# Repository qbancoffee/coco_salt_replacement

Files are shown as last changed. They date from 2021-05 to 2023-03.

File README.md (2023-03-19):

# Drop in replacement board for the custom SALT chip on the CoCo's

- [Installation instructions](https://github.com/qbancoffee/coco_salt_replacement/wiki/Installing-a-pepper-board)
- [View PDF version of the schematic](pepper_schematic.pdf)
- [Download the latest release](https://github.com/qbancoffee/coco_salt_replacement/releases/latest)
- [How to order from JLCPCB](#Ordering-the-board)
- [Peppers in the wild](#Peppers-In-The-Wild)

This board replaces the functionality of the SALT chip in the CoCo (CoCo 2 in my case). 
The SALT chip (Supply and Level Translator) is responsible for supply regulation, RS-232
interface, level translation, cassette read operations, and driving the cassette relay.

I designed it using available parts from JLCPCB to reduce assembly time and to bring down the cost.

## Goals
- [x] Power regulation with a switching regulator instead of a linear regulator.
- [x] RS232 interface.
- [x] Zero crossing detector to read cassette data.
- [x] Cassette relay control.

All goals were met!!!<br>
[Video testing the SALT replacement board AKA the PEPPER board](https://youtu.be/D6V6HFp6FHY)

## Layout
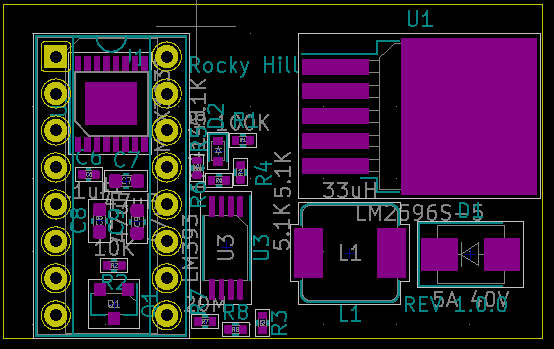
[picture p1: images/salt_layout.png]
Layout Component layout


## 3D rendering and pictures of it installed
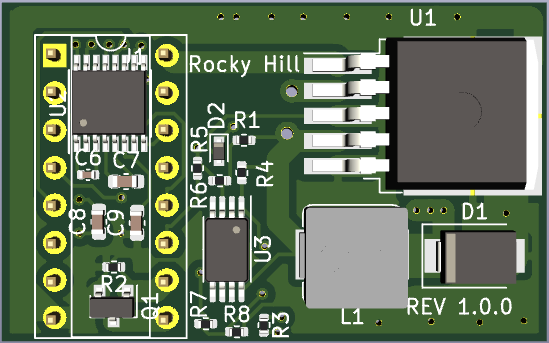
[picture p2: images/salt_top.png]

<br>
<br>
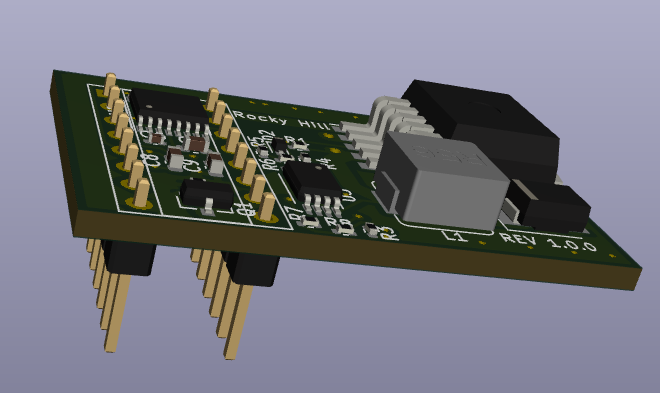
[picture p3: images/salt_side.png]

<br>
CoCo 2 with SALT chip top view rendering
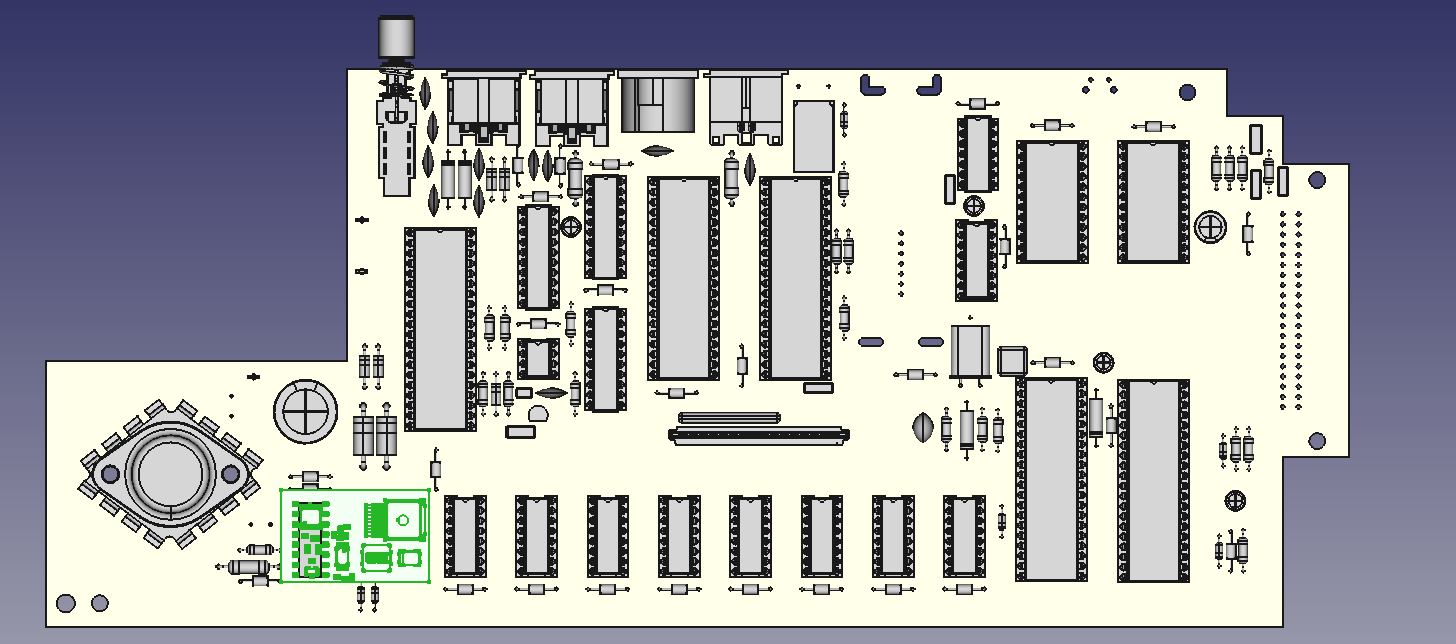
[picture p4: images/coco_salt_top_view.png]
CoCo2 with SALT chip top view

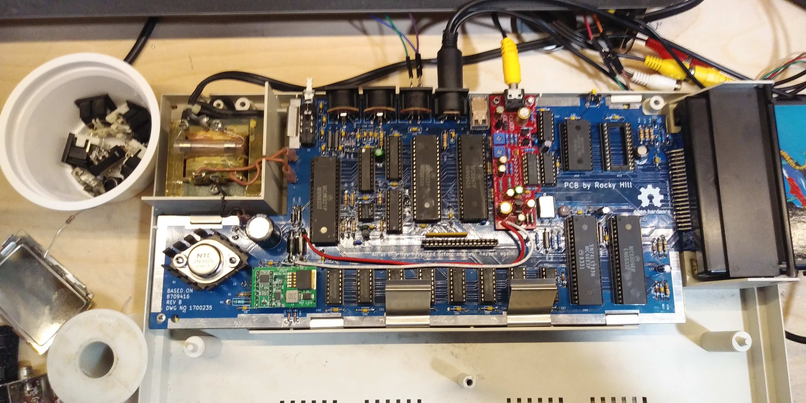
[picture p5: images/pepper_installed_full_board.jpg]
Pepper installed

<br>
CoCo 2 with SALT chip side view rendering
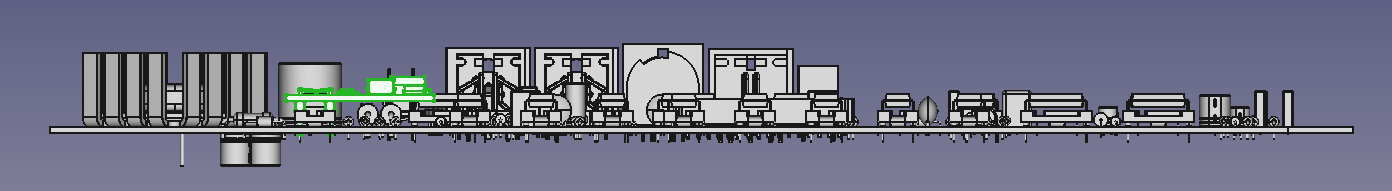
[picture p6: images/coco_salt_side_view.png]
CoCo2 with SALT chip side view

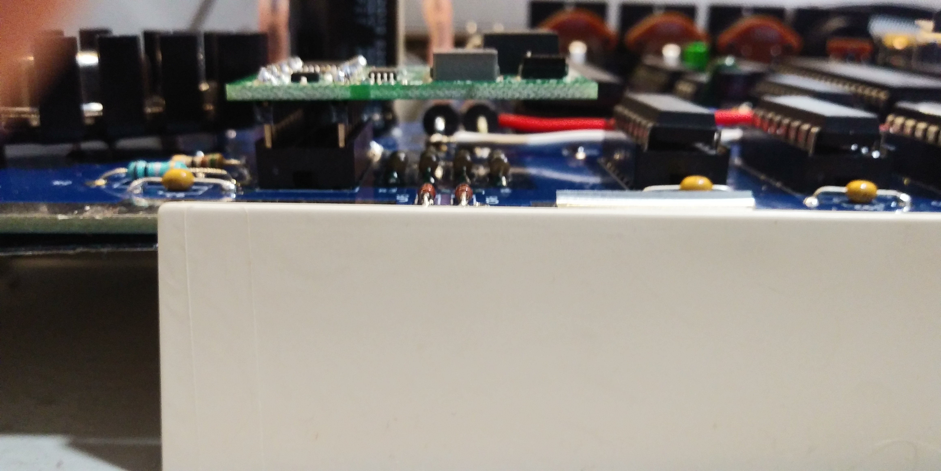
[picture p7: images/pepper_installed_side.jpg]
CoCo2 with PEPPER board side view pic


## SALT and PEPPER
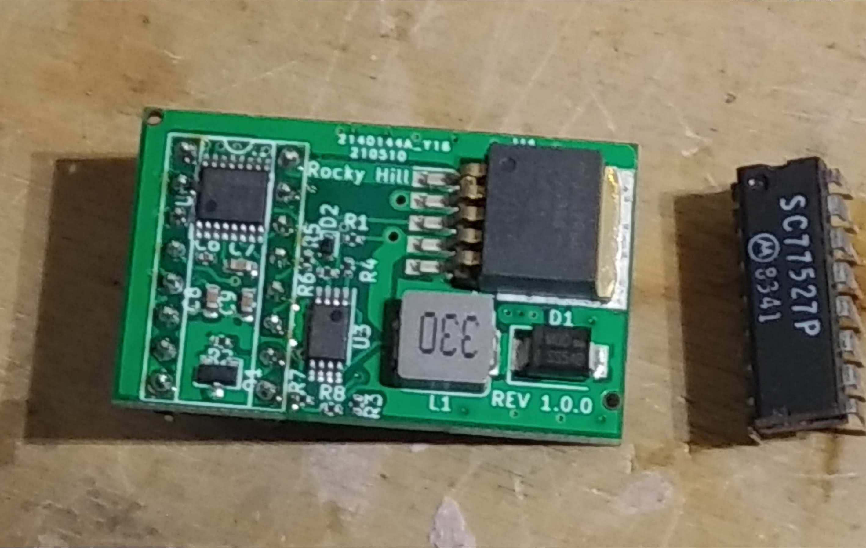
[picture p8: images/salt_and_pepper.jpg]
SALT and PEPPER


## Ordering the board
First Thing to do is clone this repository or download the latest release.
- [Download the latest release](https://github.com/qbancoffee/coco_salt_replacement/releases/latest)<br>
All the files you'll need are in the gerber folder.

Many PCB manufacturers provide proprietary EDA software with nice and helpful features to help the user decrease the time and difficulty when designing a PCB. Unfortunately sometimes these programs will only allow you to order from that specific manufacturer. This is good for the manufacturer because it increases the odds that the person will order from them again because of the amount of time invested in learning to use that specific EDA program.

There are very nice EDA programs that will allow to design a PCB really quickly with fewer errors when it comes to components and footprints. Some of these programs are free to download and use for a trial period but after finishing your design sometimes you'll find that in order to export your design files so that you can actually order the boards you have to purchase a license. Sometimes you'll also find that there is a total area limit on the size of your design unless you buy a license. Companies use these tactics to make money and I really can't blame them because they have to make a living somehow.

I guess the question you might be asking is "Is there a specific PCB manufacturer I must use for a PCB designed with KiCAD?" The answer is no.
PCB manufacturers will still take your business even if you've elected to use another piece of software for your design so long as you can provide the Gerber files for your design. The Gerber format is an open ASCII vector format for printed circuit board (PCB) designs. It is the de facto standard used by PCB industry software to describe the printed circuit board images: copper layers, solder mask, legend, drill data, etc.

KiCAD has a bit of learning curve to it but once you are familiar with its quirks you'll find that having no limits on size, layers, components ect for your design is really nice and worth your investment in time. Also, being completely free, having no vendor association, and having no licensing issues  means that you can start using right it away without worries and when you're done just create the gerber files.

You can open the PCB design and create the gerber files yourself but I've already done that for the board so all you have to do is download the zip archive and upload it to your PCB manufacturer of choice. Click on the link below to download the gerber files.
<BR>
- [Download the gerber files for version 1](https://github.com/qbancoffee/coco_salt_replacement/raw/master/pepper_v1/salt_replacement/gerber/pepper_gerber.zip)
- [Download the gerber files for version 2](https://github.com/qbancoffee/coco_salt_replacement/raw/master/pepper_v2/salt_replacement/gerber/pepper_gerber_v2.zip)

There are a ton of PCB manufactures to choose from but recently I've been using [JLPCB](https://jlcpcb.com/) because the quality is good and they are well priced. JLPCB will even provide an automated online quote for pcb manufacturing and assembly. Once ordered they should arrive in the mail.
Obviously you can use any PCB manufacturer you wish.

Some manufacturers also have assembly services with costs varying based on the number of components, packaging and size of the board. 
Surface mount components are difficult to solder onto a board by hand but are perfect for automated PCB assembly making it much cheaper when it comes to using an assembly service. I chose to design these boards using surface mount components from LCSC's inventory so that JLCPCB can mostly assemble them.

To order the components you'll need a Bill Of Materials or a BOM. I've included a BOM for the board in the repo and just like the gerber files, they will be in the repo once you download it. Click on the link below to download the BOM.
<BR>
- [View BOM for the PEPPER board version 1](https://github.com/qbancoffee/coco_salt_replacement/blob/master/pepper_v1/salt_replacement/gerber/BOM.csv)
- [View BOM for the PEPPER board version 2](https://github.com/qbancoffee/coco_salt_replacement/blob/master/pepper_v2/salt_replacement/gerber/BOM.csv)

The BOM includes LCSC part numbers so you can order them from JLCPCB, manufacturer part numbers so can search for the parts sold by other vendors, and other nice pieces of information to help you along.

To assemble the board JLCPCB will need to know the part locations and orientations, this information is in the CPL file.
- [View the CPL file for version 1](https://github.com/qbancoffee/coco_salt_replacement/blob/master/pepper_v1/salt_replacement/gerber/salt_replacement-all-pos.csv)
- [View the CPL file for version 2](https://github.com/qbancoffee/coco_salt_replacement/blob/master/pepper_v2/salt_replacement/gerber/salt_replacement_v2-all-pos.csv) 

- Go to jlcpcb and create an account if you don't have one.
- Click on "Quote Now" and then click on "Add Gerber File"
- Select "pepper_gerber.zip"
- Scroll down and select "Free SMT Assembly for your PCB order"
- Select "Assemble Top side" and agree to the terms and conditions.
- Click on "Add BOM" and select "BOM.csv"
- Click on "Add CPL file" and select "salt_replacement-all-pos.csv"
- Click "Next" and go over the components and pricing.
- Click "Next" or "Save to Cart".
  
  If you like the price, order it and you should receive a mostly assembled board.
  
Beacuse they are through hole components you'll have to solder the pin headers yourself. However, I just found out that JLCPCB offers hand soldering services now so you may want to look into that.....
  
  If you don't have 2.54 mm pitch breakaway pin headers laying around you can order from many places.
  - Amazon
  - Digikey
  - Mouser
  
  Here is a machine pin version which works better for the different type of sockets out there.<br>
  https://www.ebay.com/itm/155119535147<br>
  Thanks for the suggestion RETRO Innovations!
    
  ## Peppers In The Wild
  [Junkman testing his pepper board](https://toobnix.org/w/trVFnngNR2Q8xo4Xgh9rEd)

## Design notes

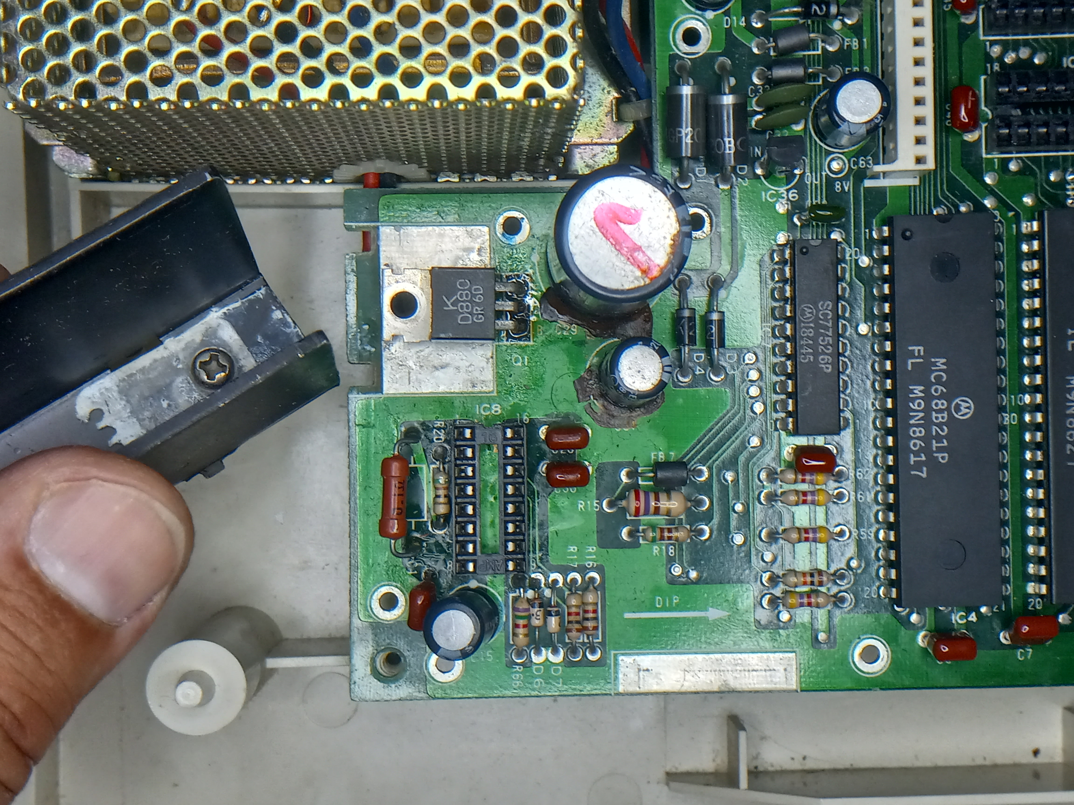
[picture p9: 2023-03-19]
images/removing_heat_sink.jpg

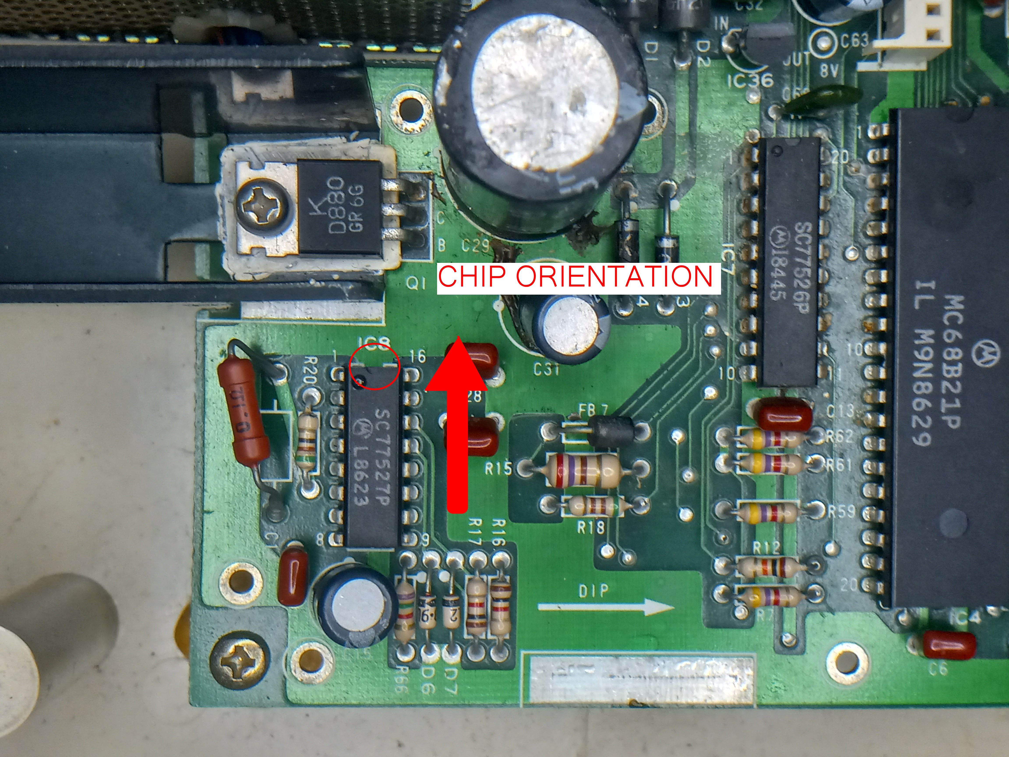
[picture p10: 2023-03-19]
images/salt_zoomed_in.jpg

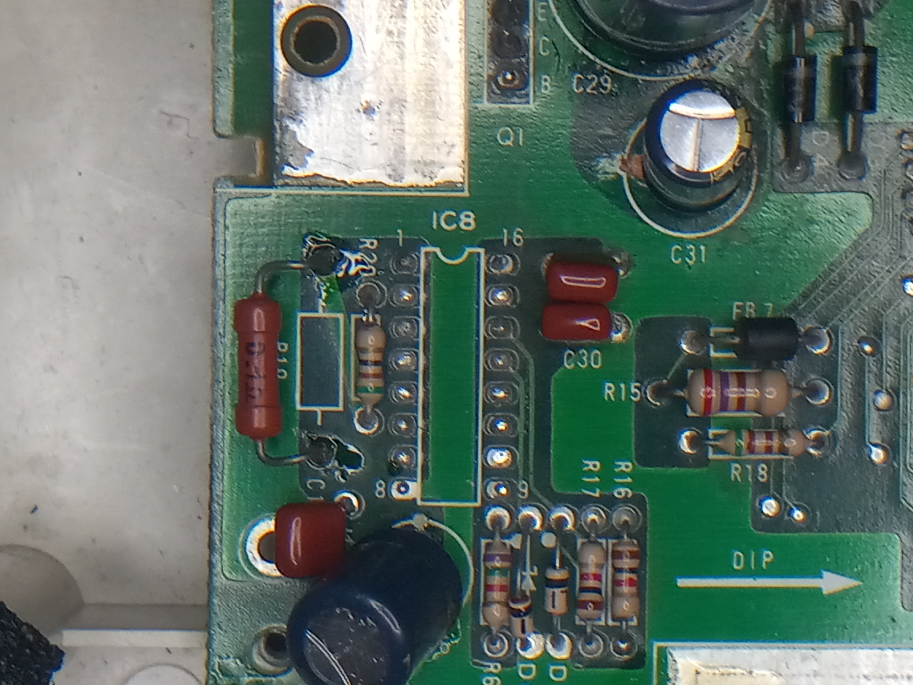
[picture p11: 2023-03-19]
images/salt_socket_removed.jpg

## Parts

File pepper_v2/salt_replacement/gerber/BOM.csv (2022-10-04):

Reference | Quantity | Value | Footprint | Datasheet | Manufacturer part# | Vendor | Vendor part#
C6 | 1 | .1uF | Capacitor_SMD:C_0402_1005Metric | https://datasheet.lcsc.com/szlcsc/1912111437_TDK-C1005X7R1H104KT000F_C361198.pdf | C1005X7R1H104KT000F | JLCPCB | C1525
C9 C7 C8 | 3 | .47uF | Capacitor_SMD:C_0603_1608Metric | https://datasheet.lcsc.com/lcsc/1810261513_Samsung-Electro-Mechanics-CL10B474KA8NNNC_C1623.pdf | CL10B474KA8NNNC | LCSC | C1623
D1 | 1 | 5A 40V | Diode_SMD:D_SMA | https://datasheet.lcsc.com/lcsc/2011241905_MDD-Microdiode-Electronics-SS54B_C32513.pdf | SS54 | JLCPCB | C22452
D2 | 1 | 1N4148WS | Diode_SMD:D_SOD-323 | https://datasheet.lcsc.com/lcsc/1810101110_Jiangsu-Changjing-Electronics-Technology-Co---Ltd--1N4148WS_C2128.pdf | 1N4148WS | JLCPCB | C2128
J1 | 1 | SALT chip package pins | Package_DIP:DIP-16_W7.62mm_Socket | DNI | DNI | DNI | DNI
L1 | 1 | 33uH | Inductor_SMD:L_Sumida_CDMC6D28_7.25x6.5mm | https://datasheet.lcsc.com/lcsc/1912111437_Chilisin-Elec-MHCI06030-330M-R8_C329385.pdf | YSPI0740-330M | LSCSC | C718398
Q1 | 1 | MMBT9014C | Package_TO_SOT_SMD:SOT-23 | https://www.onsemi.com/pub/Collateral/BC818-D.pdf | MMBT9014C | LCSC | C90157
R1 R3 | 2 | 100K | Resistor_SMD:R_0402_1005Metric | https://datasheet.lcsc.com/lcsc/1810111814_UNI-ROYAL-Uniroyal-Elec-0402WGF1003TCE_C25741.pdf | 0402WGF1003TCE | LCSC | C25741
R2 R8 | 2 | 10K | Resistor_SMD:R_0402_1005Metric | https://datasheet.lcsc.com/lcsc/1809301717_UNI-ROYAL-Uniroyal-Elec-0402WGF1002TCE_C25744.pdf | 0402WGF1002TCE | LCSC | C25744
R6 R5 R4 | 3 | 5.1K | Resistor_SMD:R_0402_1005Metric | https://datasheet.lcsc.com/lcsc/1810301112_UNI-ROYAL-Uniroyal-Elec-0402WGF5101TCE_C25905.pdf | 0402WGF5101TCE | LCSC | C25905
R7 | 1 | 20M | Resistor_SMD:R_0402_1005Metric | https://datasheet.lcsc.com/szlcsc/Uniroyal-Elec-0402WGJ0206TCE_C75135.pdf | 0402WGJ0206TCE | LCSC | C75135
U1 | 1 | LM2596S-5 | Package_TO_SOT_SMD:TO-263-5_TabPin3 | http://www.ti.com/lit/ds/symlink/lm2596.pdf | LM2596SX-5.0/NOPB | LCSC | C10002
U2 | 1 | MAX3232 | Package_SO:TSSOP-16-1EP_4.4x5mm_P0.65mm | http://www.ti.com/general/docs/suppproductinfo.tsp?distId=10 | MAX3232EUE+T | LCSC | C19767
U3 | 1 | LM393 | Package_SO:SOIC-8-1EP_3.9x4.9mm_P1.27mm_EP2.41x3.3mm | https://datasheet.lcsc.com/lcsc/1809171611_onsemi-LM393DR2G_C7955.pdf | LM393DR2G | JLCPCB | C7955

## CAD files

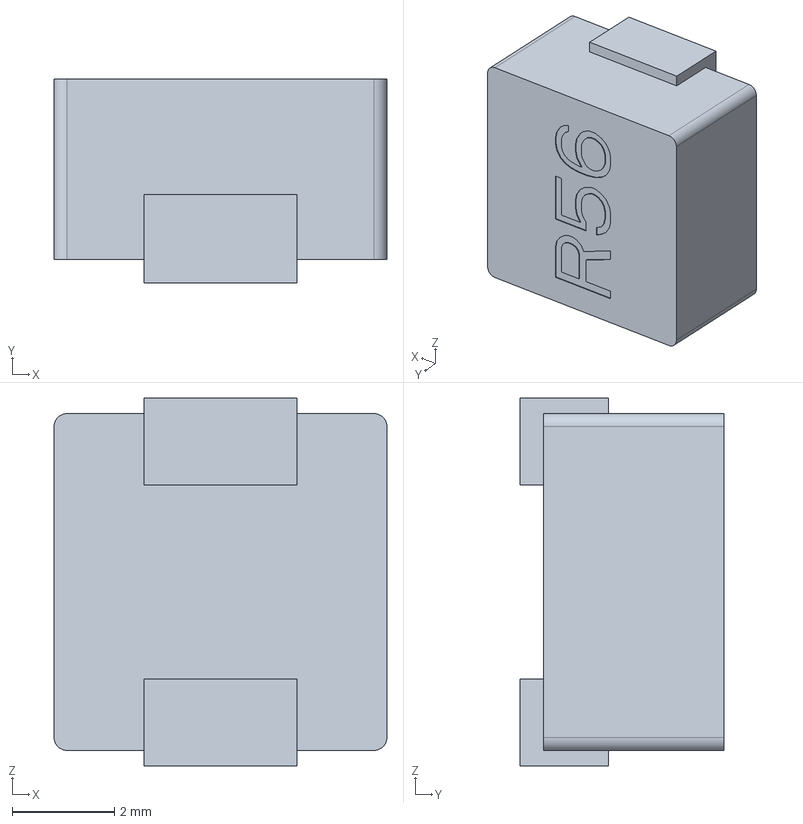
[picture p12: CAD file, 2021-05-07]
pepper_v2/3d-models/SRP6540.stp
6.50 x 3.99 x 7.19 mm

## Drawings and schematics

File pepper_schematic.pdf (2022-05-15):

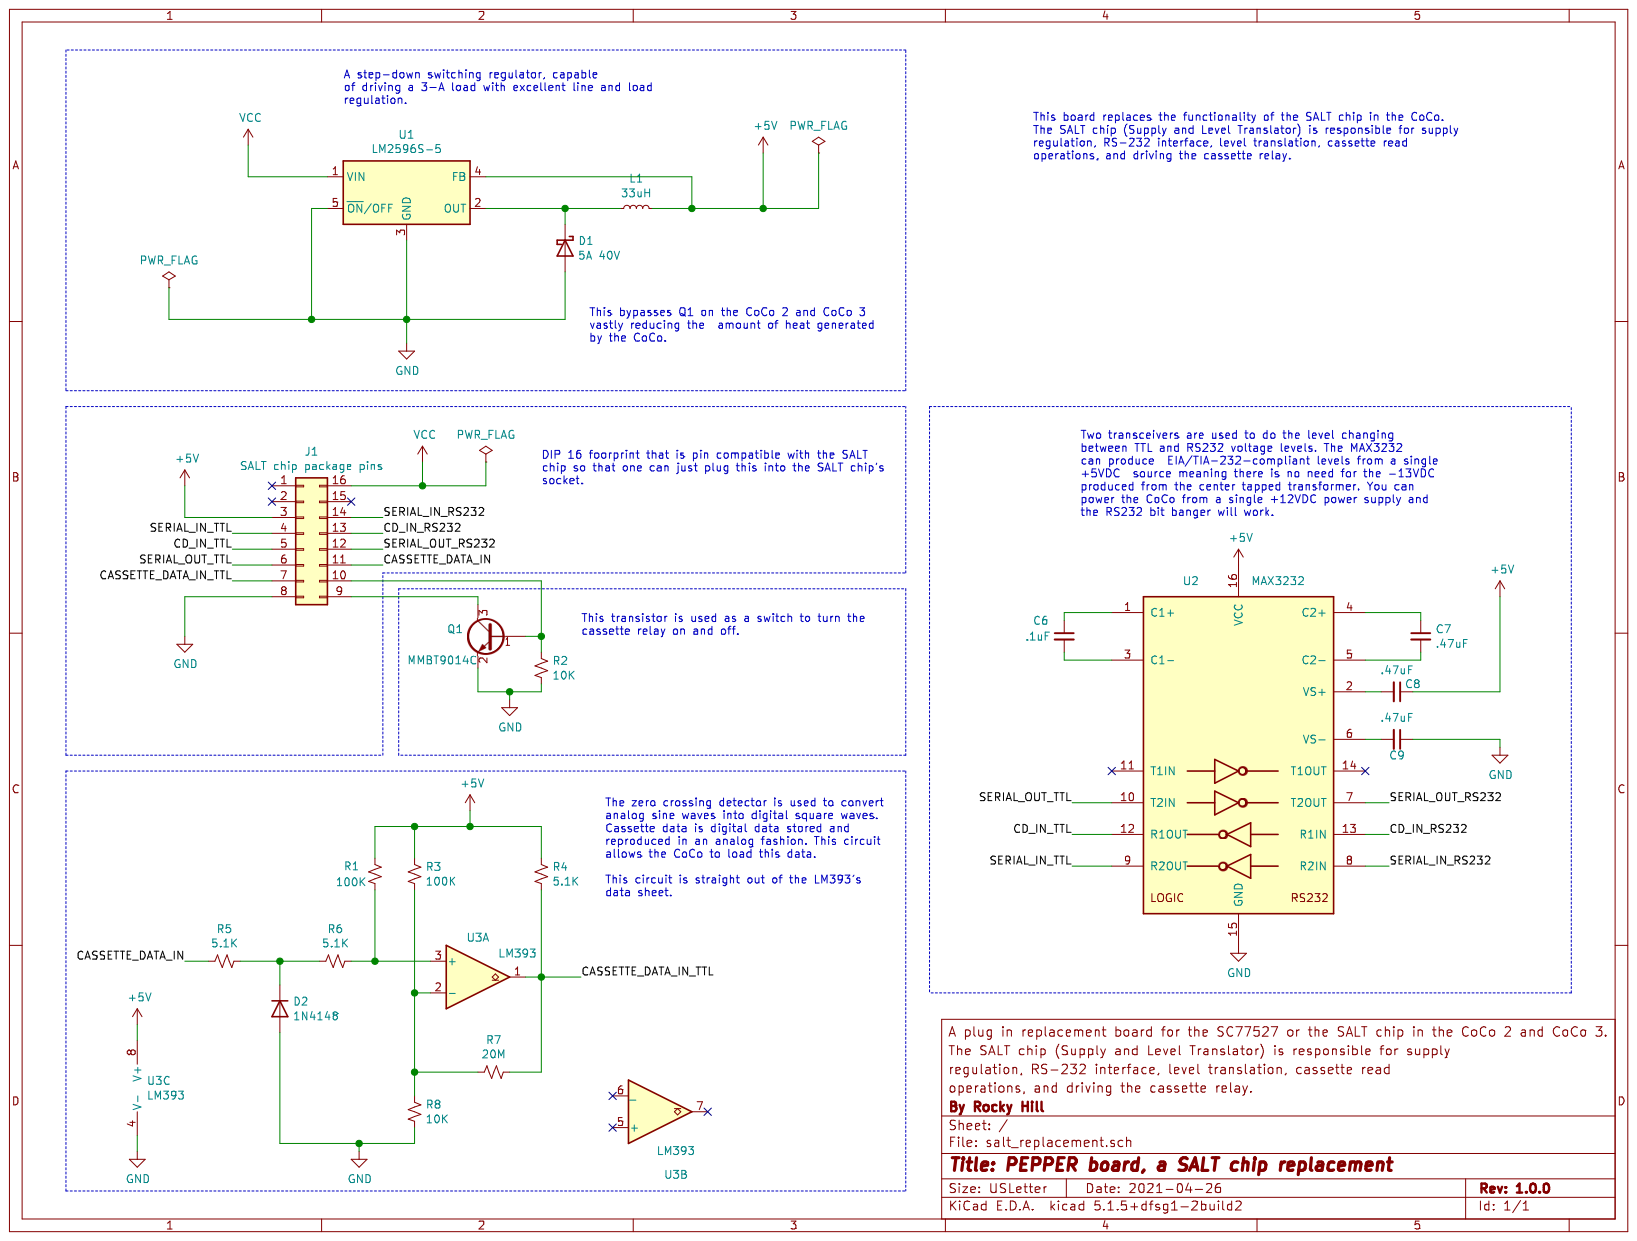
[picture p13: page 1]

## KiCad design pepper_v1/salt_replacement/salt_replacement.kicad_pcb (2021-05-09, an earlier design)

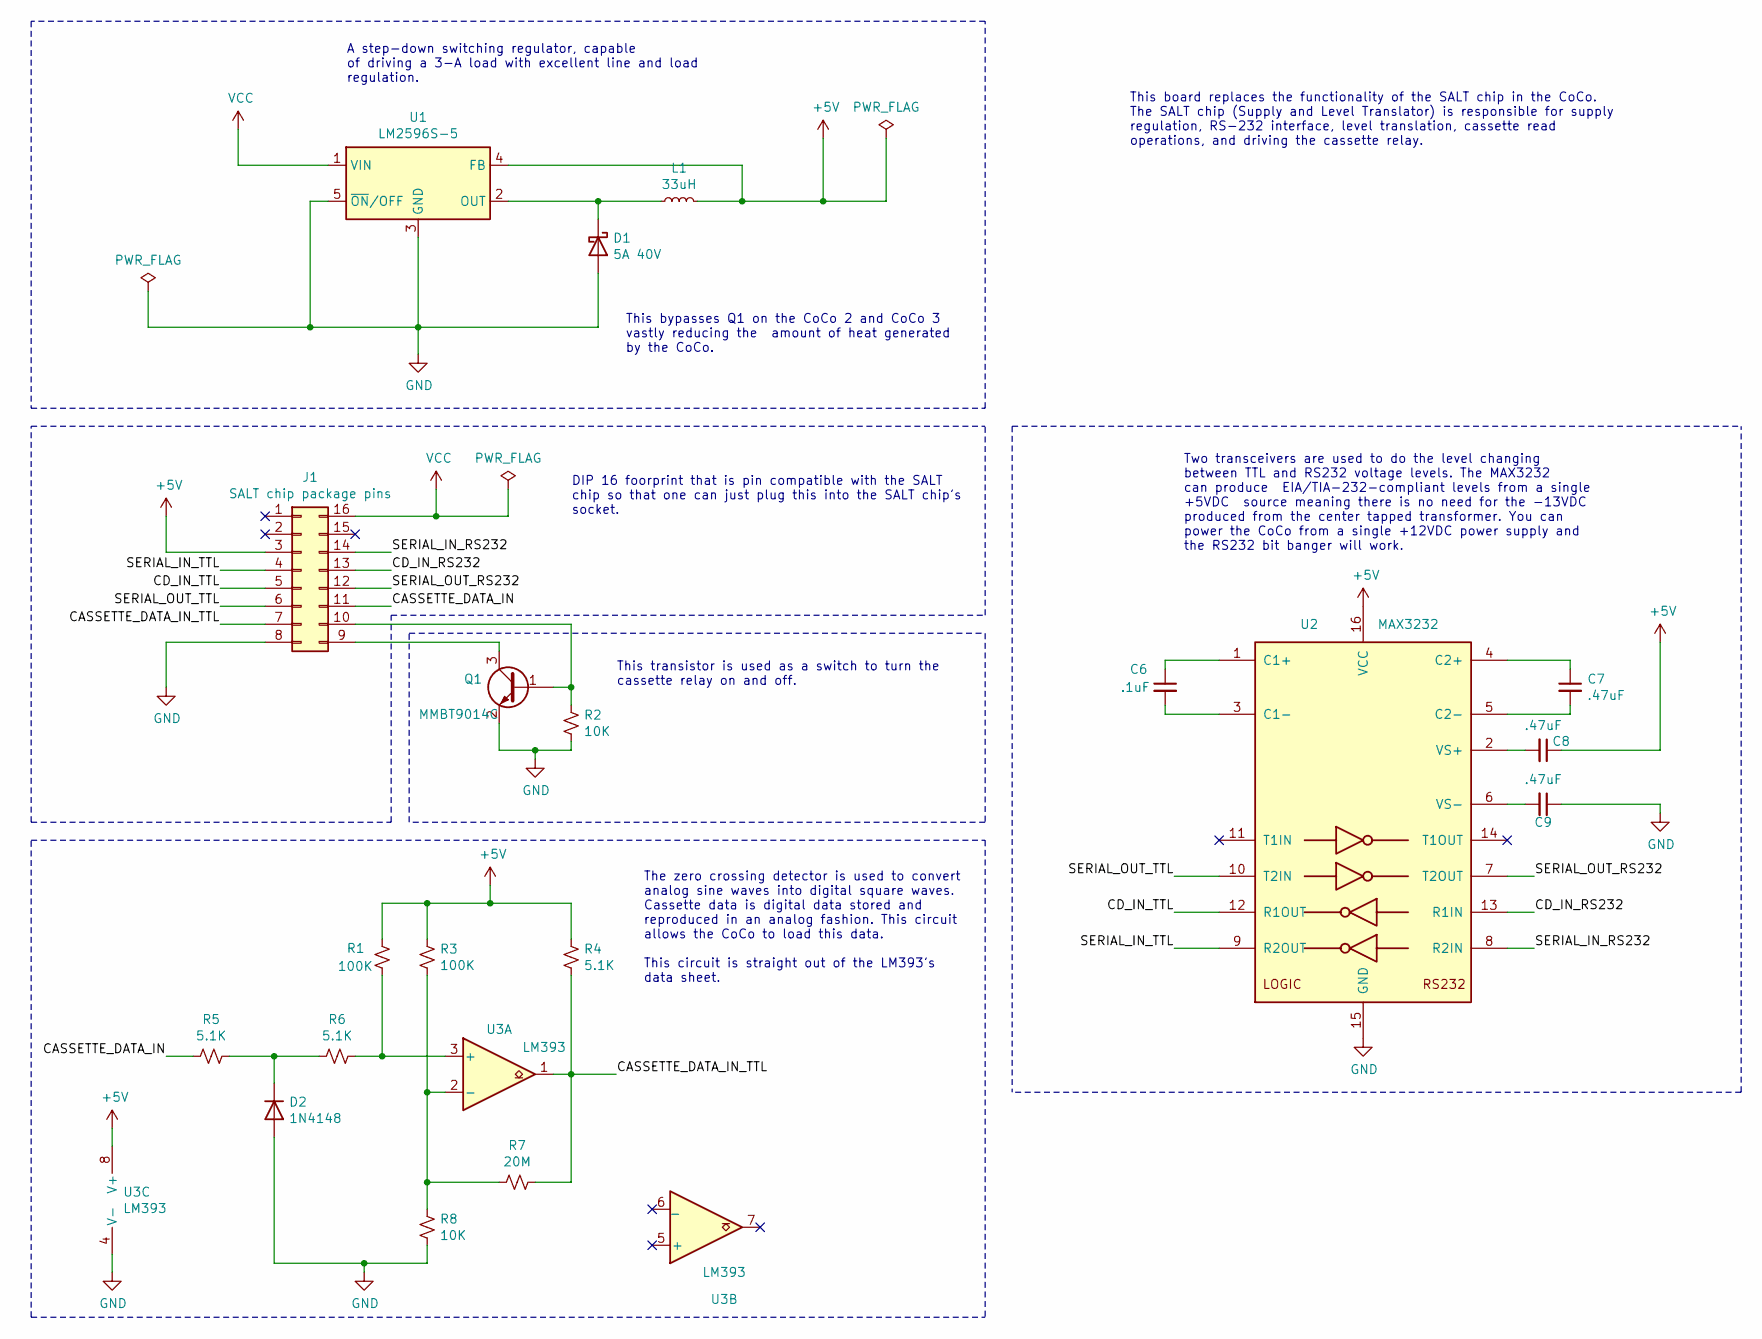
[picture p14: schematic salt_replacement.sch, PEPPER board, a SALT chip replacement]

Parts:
C6: .1uF; C_0402_1005Metric; Manufacturer part# C1005X7R1H104KT000F
C7, C8, C9: .47uF; C_0603_1608Metric; Manufacturer part# CL10B474KA8NNNC
D1: 5A 40V; D_SMB; Manufacturer part# SS54B
D2: 1N4148; D_SOD-523; Manufacturer part# 1N4148WT
J1: SALT chip package pins; DIP-16_W7.62mm_Socket; Manufacturer part# DNI
L1: 33uH; L_Sumida_CDMC6D28_7.25x6.5mm; Manufacturer part# YSPI0740-330M
Q1: MMBT9014C; SOT-23; Manufacturer part# MMBT9014C
R1, R3: 100K; R_0402_1005Metric; Manufacturer part# 0402WGF1003TCE
R2, R8: 10K; R_0402_1005Metric; Manufacturer part# 0402WGF1002TCE
R4, R5, R6: 5.1K; R_0402_1005Metric; Manufacturer part# 0402WGF5101TCE
R7: 20M; R_0402_1005Metric; Manufacturer part# 0402WGJ0206TCE
U1: LM2596S-5; TO-263-5_TabPin3; Manufacturer part# LM2596SX-5.0/NOPB
U2: MAX3232; TSSOP-16-1EP_4.4x5mm_P0.65mm; Manufacturer part# MAX3232EUE+T
U3: LM393; TSSOP-8_4.4x3mm_P0.65mm; Manufacturer part# LM393PT

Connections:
+5V: C8.1, J1.3, L1.2, R1.1, R3.1, R4.1, U1.4 (FB), U2.16 (VCC), U3.8 (V+)
/CASSETTE_DATA_IN: J1.11, R5.2
/CASSETTE_DATA_IN_TTL: J1.7, R4.2, R7.1, U3.1
/CD_IN_RS232: J1.13, U2.13 (R1IN)
/CD_IN_TTL: J1.5, U2.12 (R1OUT)
/SERIAL_IN_RS232: J1.14, U2.8 (R2IN)
/SERIAL_IN_TTL: J1.4, U2.9 (R2OUT)
/SERIAL_OUT_RS232: J1.12, U2.7 (T2OUT)
/SERIAL_OUT_TTL: J1.6, U2.10 (T2IN)
GND: C9.1, D1.2 (A), D2.2 (A), J1.8, Q1.2 (E), R2.2, R8.2, U1.3 (GND), U1.5 (~ON~/OFF), U2.15 (GND), U3.4 (V-)
unnamed: C6.1, U2.1 (C1+)
unnamed: C6.2, U2.3 (C1-)
unnamed: C7.1, U2.4 (C2+)
unnamed: C7.2, U2.5 (C2-)
unnamed: C8.2, U2.2 (VS+)
unnamed: C9.2, U2.6 (VS-)
unnamed: D1.1 (K), L1.1, U1.2 (OUT)
unnamed: D2.1 (K), R5.1, R6.2
unnamed: J1.9, Q1.3 (C)
unnamed: J1.10, Q1.1 (B), R2.1
unnamed: R1.2, R6.1, U3.3 (+)
unnamed: R3.2, R7.2, R8.1, U3.2 (-)
VCC: J1.16, U1.1 (VIN)

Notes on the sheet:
A step-down switching regulator, capable of driving a 3-A load with excellent line and load regulation.
This bypasses Q1 on the CoCo 2 and CoCo 3 vastly reducing the amount of heat generated by the CoCo.
This transistor is used as a switch to turn the cassette relay on and off.
DIP 16 foorprint that is pin compatible with the SALT chip so that one can just plug this into the SALT chip's socket.
Two transceivers are used to do the level changing between TTL and RS232 voltage levels. The MAX3232 can produce EIA/TIA-232-compliant levels from a single +5VDC source meaning there is no need for the -13VDC produced from the center tapped transformer. You can power the CoCo from a single +12VDC p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
The zero crossing detector is used to convert analog sine waves into digital square waves. Cassette data is digital data stored and reproduced in an analog fashion. This circuit allows the CoCo to load this data. This circuit is straight out of the LM393's data sheet.
This board replaces the functionality of the SALT chip in the CoCo. The SALT chip (Supply and Level Translator) is responsible for supply regulation, RS-232 interface, level translation, cassette read operations, and driving the cassette relay.

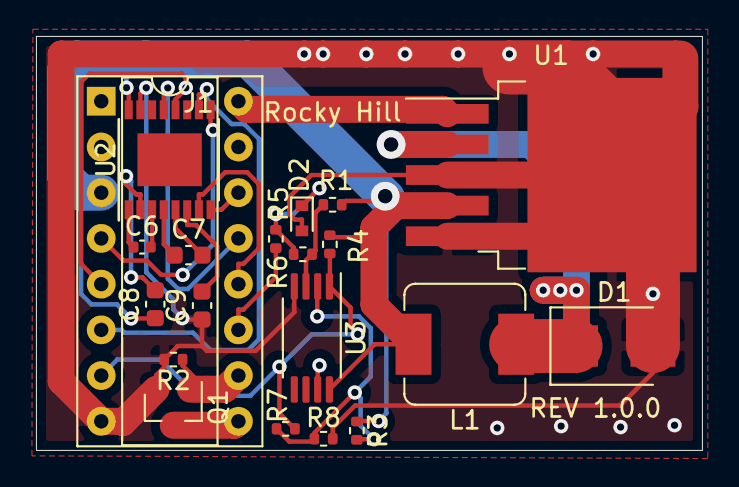
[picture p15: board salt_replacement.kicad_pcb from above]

Board: 2 copper layers, 37.0 x 23.0 mm, 20 parts (0 on the bottom side), 23 nets.

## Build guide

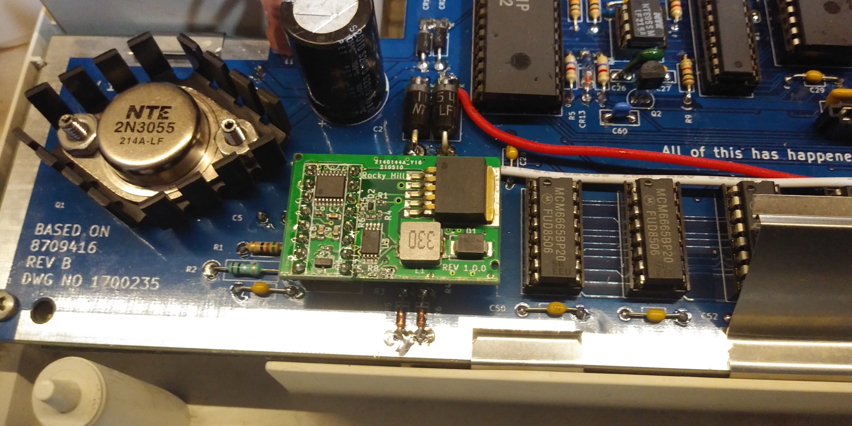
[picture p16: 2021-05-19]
images/pepper_installed.jpg

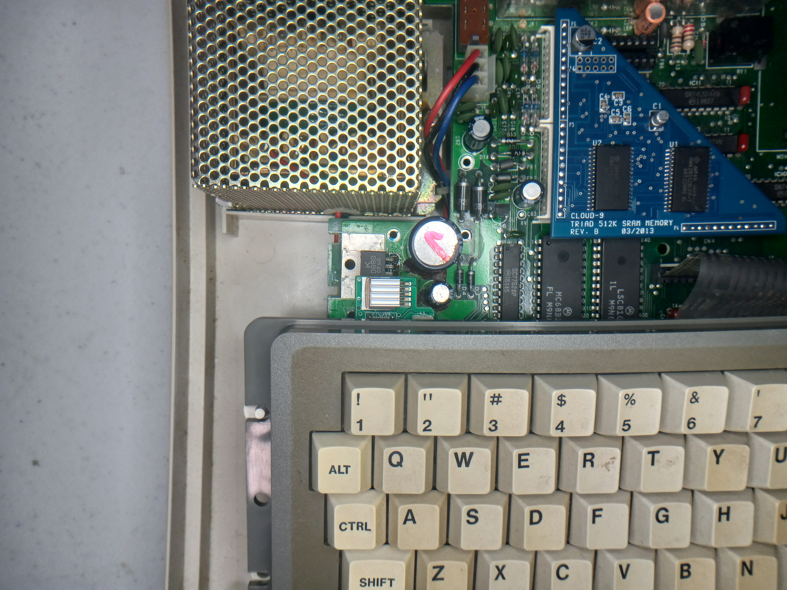
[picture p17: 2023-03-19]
images/pepper_installed_with_keyboard.jpg

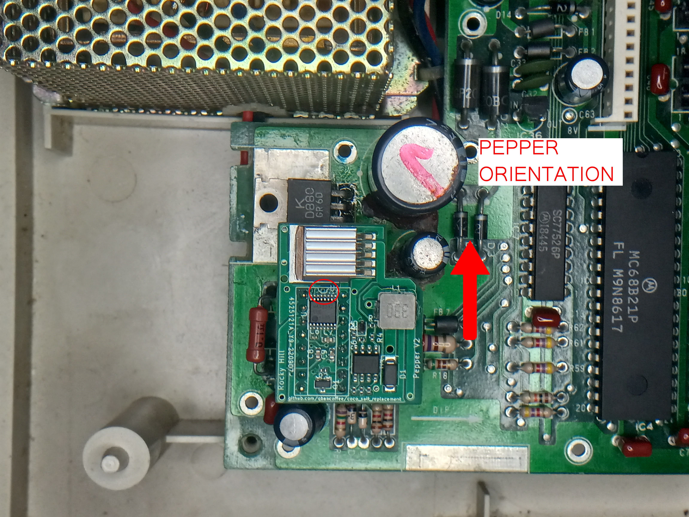
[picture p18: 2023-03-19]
images/pepper_installed_zoomed_in.jpg

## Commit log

2021-05-07 -added more components -started making the PCB
    [SRP6540.stp, salt_replacement.sch]
2021-05-09 -complete redesign -replaced all components with jclpcb stock -added non-inverting zero crossing circuit.
    [BOM.csv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]
2021-05-21 added zip archive with gerbers
2021-05-21 moved some columns around in the BOM
    [BOM.csv]
2021-05-21 Update README.md
    Added instructions to order the boards with assembly from JLCPCB
2021-05-21 fixed gerber
2021-11-23 updated BOM with available parts from jlcpcb
    [BOM.csv, salt_replacement.sch]
2022-05-15 cleaned up schematic, added comments and added a PDF version of the schematic
    [salt_replacement.sch]
2022-10-04 added a second version of the pepper board
    [BOM.csv, SRP6540.stp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]
